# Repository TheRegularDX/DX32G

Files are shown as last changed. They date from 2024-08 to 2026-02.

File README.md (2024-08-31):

# DX32G
ESP32S3 based board with built in USB to serial adapter, micro SD card reader, and I2C OLED connection.

## Features
- WiFi and BLE
- x25 GPIO pins
- x1 WS2812B addresable RGB led
- x1 Micro SD card reader
- x1 0,96 OLED connection
- CH340N USB to serial adapter

## Programming
Supports Arduino IDE, PlattformIO and CircuitPython.

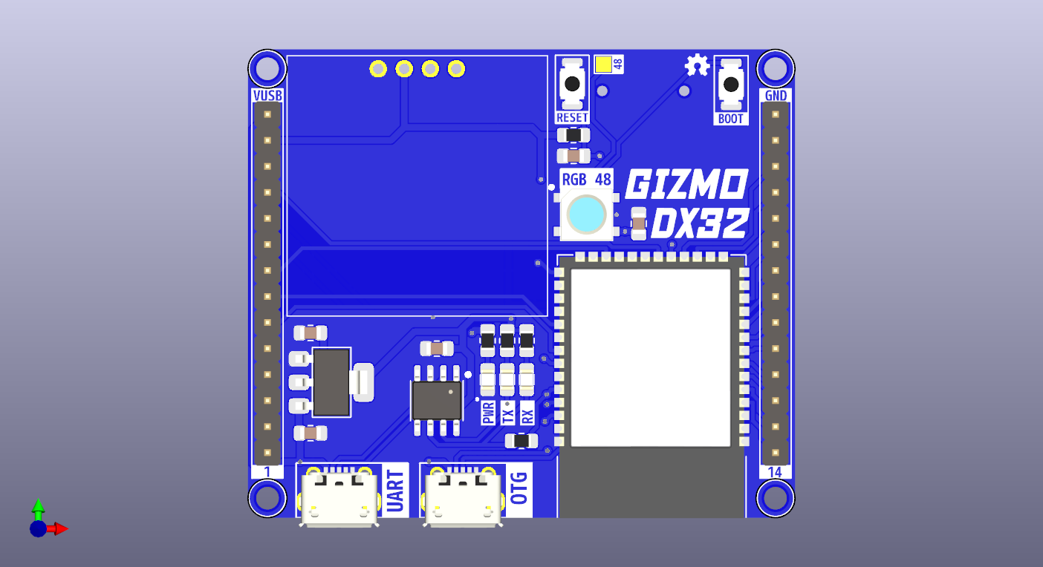
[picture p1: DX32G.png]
DX32G


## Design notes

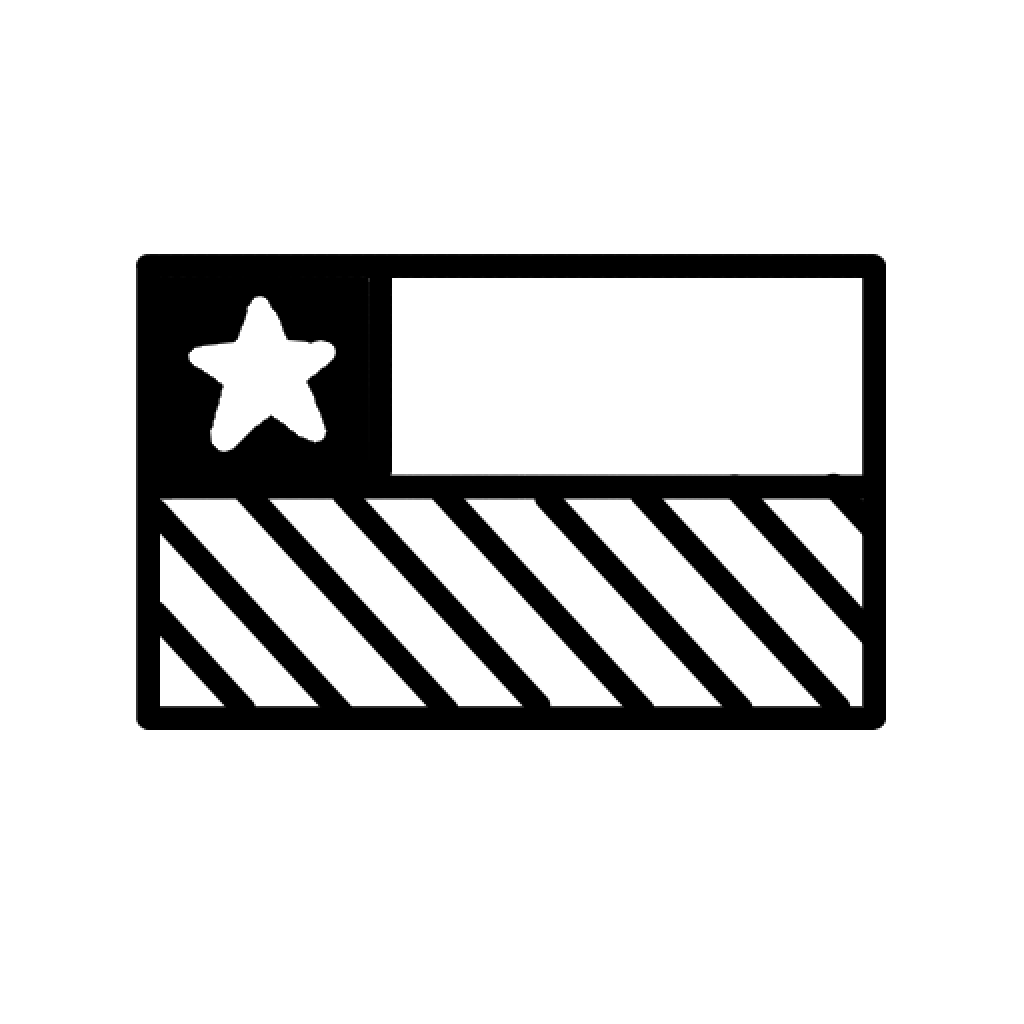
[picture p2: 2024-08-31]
flag.png

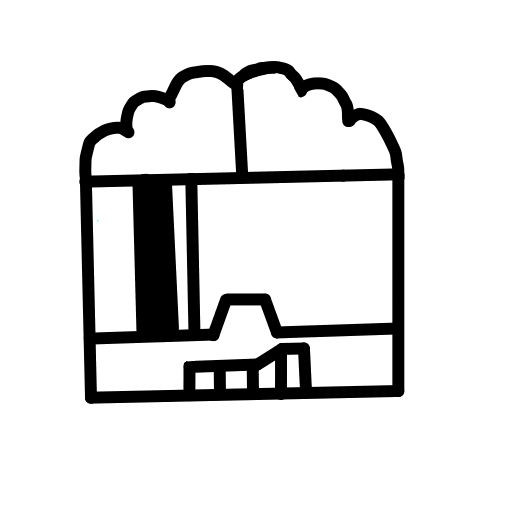
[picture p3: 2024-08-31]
transparent_lineart.png

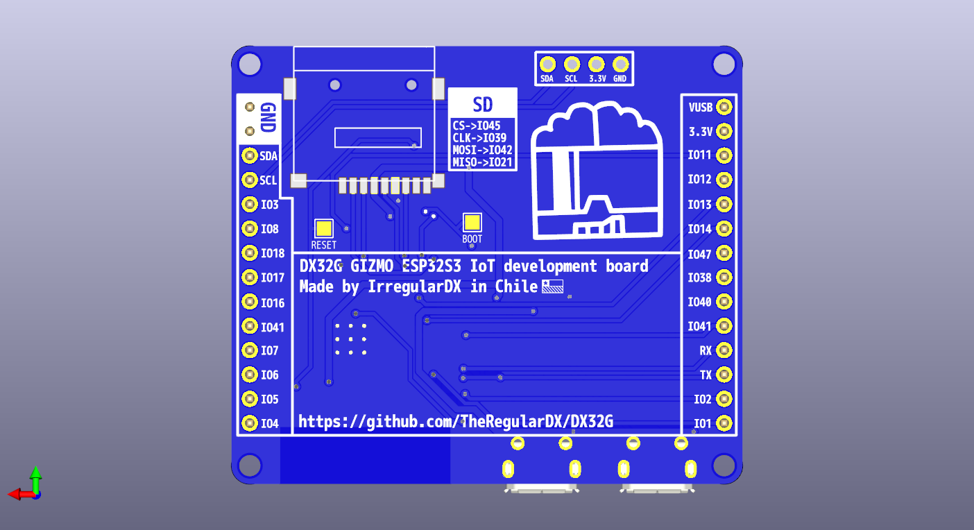
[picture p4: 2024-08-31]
DX32G_BACK.png

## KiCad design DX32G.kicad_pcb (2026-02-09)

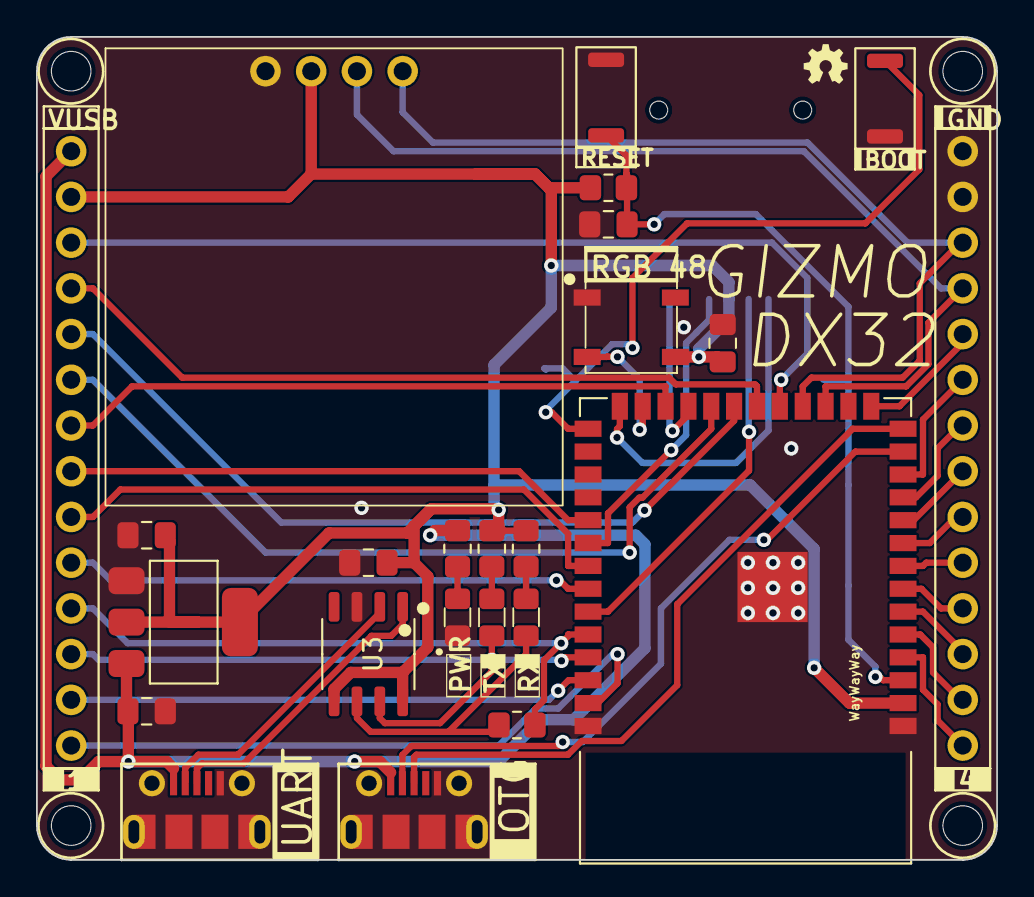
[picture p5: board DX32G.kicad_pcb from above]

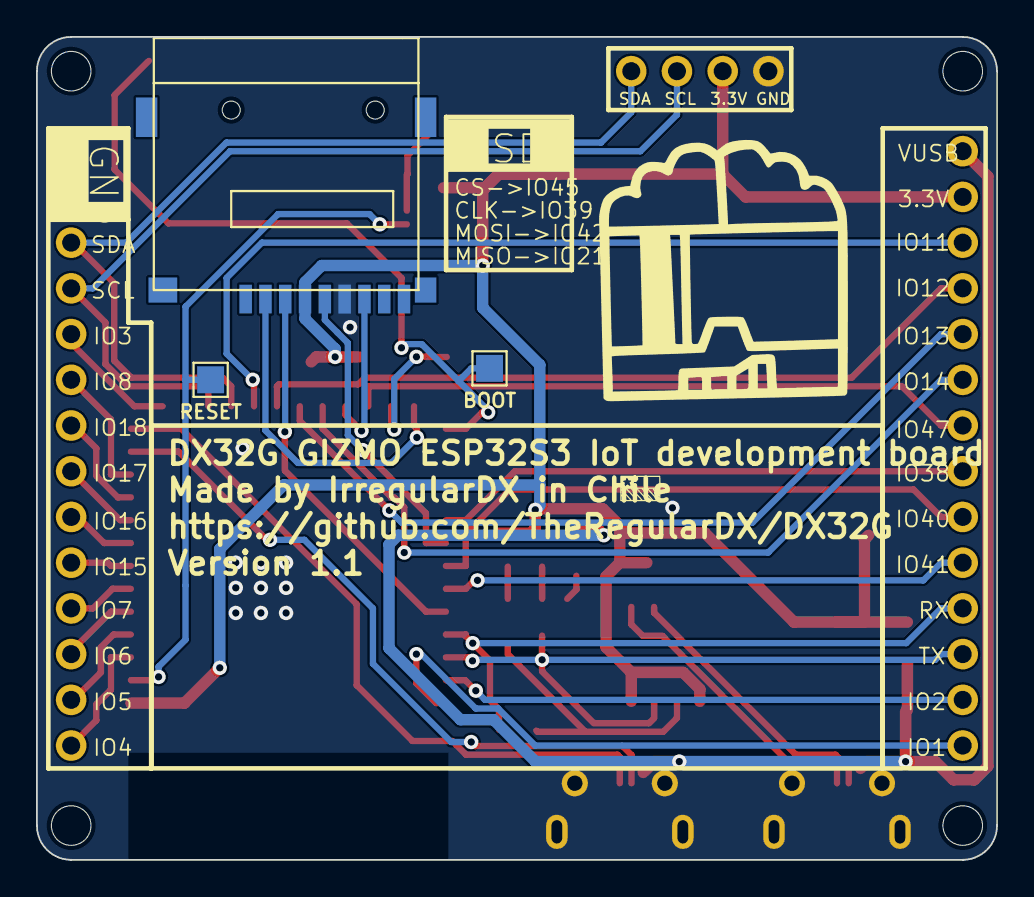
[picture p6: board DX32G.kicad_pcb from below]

Board: 2 copper layers, 53.3 x 45.7 mm, 34 parts (5 on the bottom side), 42 nets.

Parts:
BOOT: BOOT; TestPoint_Pad_1.5x1.5mm
C1: 1uF; C_0805_2012Metric_Pad1.18x1.45mm_HandSolder
C2, C3, C4, C5: 10uF; C_0805_2012Metric_Pad1.18x1.45mm_HandSolder
D1, D2, D3: LED; LED_0805_2012Metric_Pad1.15x1.40mm_HandSolder
D4: WS2812B; LED_WS2812B_PLCC4_5.0x5.0mm_P3.2mm
Flag: LOGO
HOLE: MountingHole_2.2mm_M2_DIN965
J1, J7: USB_B_Micro; USB_Micro-B_Molex-105017-0001
J2: MicroSD Card; 112J-TDAR-R01
J3: RIGHT; PinHeader_1x14_P2.54mm_Vertical
J4: LEFT; PinHeader_1x14_P2.54mm_Vertical
OSH: LOGO
R1: 10k; R_0805_2012Metric_Pad1.20x1.40mm_HandSolder
R2, R3, R4, R5: 1k; R_0805_2012Metric_Pad1.20x1.40mm_HandSolder
RESET: RESET; TestPoint_Pad_1.5x1.5mm
SW1: reset; SW_Push_SPST_NO_Alps_SKRK
SW2: boot; SW_Push_SPST_NO_Alps_SKRK
U1: ESP32-S3-WROOM-1
U2: AMS1117-3.3; SOT-223-3_TabPin2
U3: CH340N; SOP-8_3.9x4.9mm_P1.27mm
U4: SSD1306_OLED
hole2, hole3, hole4: MountingHole_2.2mm_M2_DIN965
logo: LOGO

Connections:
+3.3V: C3.1, C4.2, C5.2, D4.1 (VDD), J2.4 (4-VDD), J4.2, R1.1, R2.2, R3.2, U1.2 (3V3), U2.2 (VO), U3.5 (VCC), U3.8 (V3), U4.2 (VCC)
+5V: C2.1, J1.1 (VBUS), J4.1, J7.1 (VBUS), R5.2, U2.3 (VI)
/BOOT: BOOT.1, SW2.1, U1.27 (IO0)
/GPIO1: J4.14, U1.39 (IO1)
/GPIO2: J4.13, U1.38 (IO2)
/GPIO3: J3.10, U1.15 (IO3)
/GPIO4: J3.1, U1.4 (IO4)
/GPIO5: J3.2, U1.5 (IO5)
/GPIO6: J3.3, U1.6 (IO6)
/GPIO7: J3.4, U1.7 (IO7)
/GPIO8: J3.9, U1.12 (IO8)
/GPIO9_SCL: J3.11, U1.17 (IO9), U4.3 (SCL)
/GPIO10_SDA: J3.12, U1.18 (IO10), U4.4 (SDA)
/GPIO11: J4.3, U1.19 (IO11)
/GPIO12: J4.4, U1.20 (IO12)
/GPIO13: J4.5, U1.21 (IO13)
/GPIO14: J4.6, U1.22 (IO14)
/GPIO15: J3.5, U1.8 (IO15)
/GPIO16: J3.6, U1.9 (IO16)
/GPIO17: J3.7, U1.10 (IO17)
/GPIO18: J3.8, U1.11 (IO18)
/GPIO38: J4.8, U1.31 (IO38)
/GPIO40: J4.9, U1.33 (IO40)
/GPIO41: J4.10, U1.34 (IO41)
/GPIO47: J4.7, U1.24 (IO47)
/IO_RX: J4.11, R4.1, U1.36 (RXD0)
/IO_TX: D3.1 (K), J4.12, U1.37 (TXD0), U3.7 (RXD)
/RESET: C1.1, R1.2, RESET.1, SW1.1, U1.3 (EN)
/RGB_LED: D4.4 (DIN), U1.25 (IO48)
/SD_CLK: J2.5 (5-CLK), U1.32 (IO39)
/SD_CS: J2.2 (2-CD/DAT3), U1.26 (IO45)
/SD_MISO_DO: J2.7 (7-DAT0), U1.23 (IO21)
/SD_MOSI_DI: J2.3 (3-CMD), U1.35 (IO42)
/USB_D+: J1.3 (D+), U1.14 (IO20)
/USB_D-: J1.2 (D-), U1.13 (IO19)
GND: C1.2, C2.2, C3.2, C4.1, C5.1, D1.1 (K), D4.3 (VSS), J1.5 (GND), J1.6 (Shield), J2.6 (6-VSS), J3.13, J3.14, J7.5 (GND), J7.6 (Shield), SW1.2, SW2.2, U1.1 (GND), U1.40 (GND), U1.41 (GND), U2.1 (GND), U3.3 (GND), U4.1 (GND)
unnamed: D1.2 (A), R5.1
unnamed: D2.2 (A), R2.1
unnamed: D2.1 (K), R4.2, U3.6 (TXD)
unnamed: D3.2 (A), R3.1
unnamed: J7.3 (D+), U3.1 (UD+)
unnamed: J7.2 (D-), U3.2 (UD-)
